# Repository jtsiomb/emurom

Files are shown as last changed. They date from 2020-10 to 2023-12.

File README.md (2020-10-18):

emurom - ROM emulator board
===========================

emurom photo

The purpose of emurom is to make it fast and convenient to hack code in ROMs
without having to repeatedly remove and reprogram an actual ROM chip.

Emurom is a board which connects through USB to a host computer, and
can be connected in place of a parallel ROM chip on a target device. It acts as
a ROM chip, but holds its data in a static RAM, which can be updated at any time
through the USB connection. Optionally it can provide power (5v) to the device
by shorting a jumper, and it also has a lead to clip to the reset signal of the
target device, to automatically reboot it when a new ROM image is uploaded.

Hardware design (kicad project) is in the root directory. The firmware for the
microcontroller is located under `fw`, while in the `emurom` subdirectory, there
is a UNIX program which can be used to upload a ROM image to the device, simply
by running it with the name of the ROM image as a command line argument.

 - Project website: http://nuclear.mutantstargoat.com/hw/emurom
 - Git repository: https://github.com/jtsiomb/emurom
 - Schematic (PDF): http://nuclear.mutantstargoat.com/hw/emurom/emurom-schematic.pdf

License
-------
Copyright (C) 2020 John Tsiombikas <nuclear@member.fsf.org>

All hardware designs in this project are free/open hardware. Feel free to
manufacture, sell, use, modify and/or redistribute, under the terms of the
Creative Commons Attribution Share-Alike license (CC BY-SA). See `LICENSE.hw`
for details.

All software in this project (firmware and host upload program) are free
software. Feel free to use, modify and/or redistribute under the terms of the
GNU General Public License version 3, or at your option any later version
published by the Free Software foundation. See `LICENSE.sw` for details.

Download
--------
This git repository contains the current project files and source code for
emurom, but it does not include any binaries or build products.

The release archive includes the schematic PDF, gerber files for PCB
manufacturing, datasheets, and pre-built binaries (firmware image and host
program).

Latest release (emurom rev2):
 - emurom website: http://nuclear.mutantstargoat.com/hw/emurom/release/emurom-rev2.tar.gz
 - github mirror: https://github.com/jtsiomb/emurom/releases/download/v2/emurom-rev2.tar.gz

Bill of materials
-----------------
Emurom rev2 BOM:

|#  | name | description | package |
|---|---|---|---|
| 1 | U1 | ATmega328P AVR microcontroller | TQFP 32 |
| 1 | U2 | MCP2221 USB-serial converter | SOIC 14 |
| 1 | U3 | 74HCT157 quad 2-1 multiplexer | SOIC 16 |
| 2 | U4,U5 | 74HCT595 8-bit shift register w/3-state output | SOIC 16 |
| 1 | U6 | UM61512AK 64k static RAM (or similar 64k SRAMs)| PDIP 32 |
| 3 | U7-U9 | 74HCT244 octal 3-state buffer | SOIC 20 |
| 2 | C1,C2 | 22 pF ceramic capacitor | 0805 |
|11 | C3-C13  | 0.1 uF ceramic capacitor | 0805 |
| 2 | R1,R2 | 330 Ohm resistor | 0805 |
| 6 | R3-R8 | 4.7 kOhm resistor | 0805 |
| 2 | D1,D2 | LED | 0805 |
| 2 | D3,D4 | 1N4148 signal diodes | 0805 |
| 1 | Y1 | 14.7456 quartz crystal | 7.6x4.1mm SMD |
| 3 | JP1-JP3 | 2-pin male header (jumper pins) | |
| 1 | J1 | 6-pin (2x3) male header or IDC conn. 2.54mm pitch | |
| 1 | J2 | molex 105017-1001 micro-USB (type B) connector | |
| 1 | U10,J3  | 24-pin (2x12) male header or IDC conn. 2.54mm pitch | |
| 1 | U11,J5  | 28-pin (2x14) male header or IDC conn. 2.54mm pitch | |
| 1 | J7 | 1-pin male header | |

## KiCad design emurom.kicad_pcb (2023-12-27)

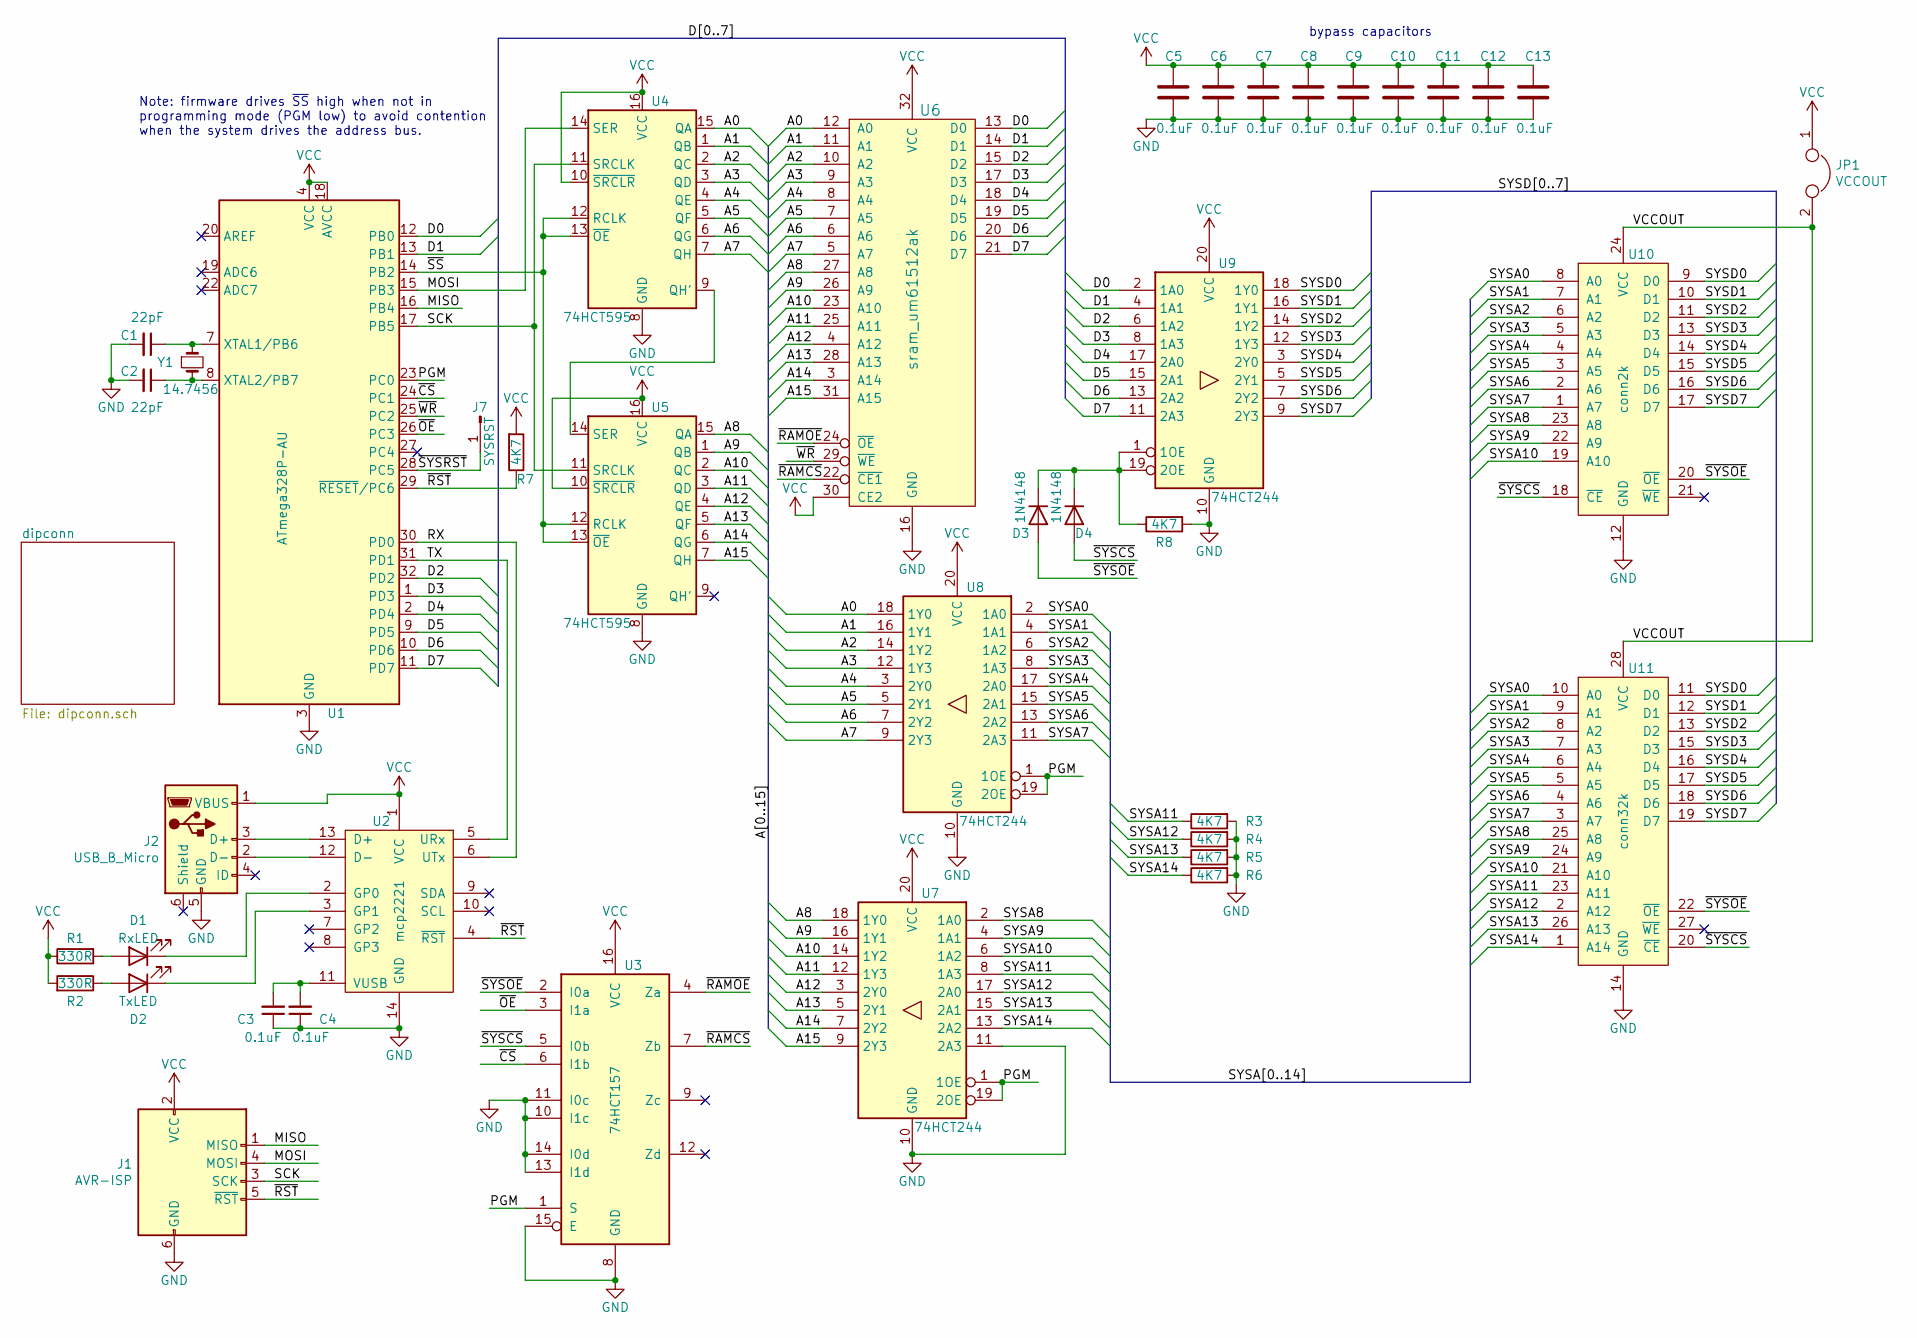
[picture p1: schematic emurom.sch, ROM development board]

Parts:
C1, C2: 22pF; C_0805_2012Metric_Pad1.15x1.40mm_HandSolder
C3, C4, C5, C6, C7, C8, C9, C10, C11, C12, C13: 0.1uF; C_0805_2012Metric_Pad1.15x1.40mm_HandSolder
D1: RxLED; LED_0805_2012Metric_Pad1.15x1.40mm_HandSolder
D2: TxLED; LED_0805_2012Metric_Pad1.15x1.40mm_HandSolder
D3, D4: 1N4148; D_0805_2012Metric_Pad1.15x1.40mm_HandSolder
J1: AVR-ISP; IDC-Header_2x03_P2.54mm_Vertical
J2: USB_B_Micro; USB_Micro-B_Molex-105017-0001
J7: SYSRST; PinSocket_1x01_P2.54mm_Vertical
JP1: VCCOUT; PinHeader_1x02_P2.54mm_Vertical
R1, R2: 330R; R_0805_2012Metric_Pad1.15x1.40mm_HandSolder
R3, R4, R5, R6, R7, R8: 4K7; R_0805_2012Metric_Pad1.15x1.40mm_HandSolder
U1: ATmega328P-AU; TQFP-32_7x7mm_P0.8mm
U2: mcp2221; SOIC-14_3.9x8.7mm_P1.27mm
U3: 74HCT157; SOIC-16_4.55x10.3mm_P1.27mm
U4, U5: 74HCT595; SOIC-16_3.9x9.9mm_P1.27mm
U6: sram_um61512ak; DIP-32_W7.62mm
U7, U8, U9: 74HCT244; SOIC-20W_7.5x12.8mm_P1.27mm
U10: conn2k
U11: conn32k
Y1: 14.7456; Crystal_SMD_ECS_CSM3X-2Pin_7.6x4.1mm

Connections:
/A0: U4.15 (QA), U6.12 (A0), U8.18 (1Y0)
/A1: U4.1 (QB), U6.11 (A1), U8.16 (1Y1)
/A2: U4.2 (QC), U6.10 (A2), U8.14 (1Y2)
/A3: U4.3 (QD), U6.9 (A3), U8.12 (1Y3)
/A4: U4.4 (QE), U6.8 (A4), U8.3 (2Y0)
/A5: U4.5 (QF), U6.7 (A5), U8.5 (2Y1)
/A6: U4.6 (QG), U6.6 (A6), U8.7 (2Y2)
/A7: U4.7 (QH), U6.5 (A7), U8.9 (2Y3)
/A8: U5.15 (QA), U6.27 (A8), U7.18 (1Y0)
/A9: U5.1 (QB), U6.26 (A9), U7.16 (1Y1)
/A10: U5.2 (QC), U6.23 (A10), U7.14 (1Y2)
/A11: U5.3 (QD), U6.25 (A11), U7.12 (1Y3)
/A12: U5.4 (QE), U6.4 (A12), U7.3 (2Y0)
/A13: U5.5 (QF), U6.28 (A13), U7.5 (2Y1)
/A14: U5.6 (QG), U6.3 (A14), U7.7 (2Y2)
/A15: U5.7 (QH), U6.31 (A15), U7.9 (2Y3)
/D0: U1.12 (PB0), U6.13 (D0), U9.2 (1A0)
/D1: U1.13 (PB1), U6.14 (D1), U9.4 (1A1)
/D2: U1.32 (PD2), U6.15 (D2), U9.6 (1A2)
/D3: U1.1 (PD3), U6.17 (D3), U9.8 (1A3)
/D4: U1.2 (PD4), U6.18 (D4), U9.17 (2A0)
/D5: U1.9 (PD5), U6.19 (D5), U9.15 (2A1)
/D6: U1.10 (PD6), U6.20 (D6), U9.13 (2A2)
/D7: U1.11 (PD7), U6.21 (D7), U9.11 (2A3)
/MISO: J1.1 (MISO), U1.16 (PB4)
/MOSI: J1.4 (MOSI), U1.15 (PB3), U4.14 (SER)
/PGM: U1.23 (PC0), U3.1 (S), U7.1 (1OE), U7.19 (2OE), U8.1 (1OE), U8.19 (2OE)
/RX: U1.30 (PD0), U2.6 (UTx)
/SCK: J1.3 (SCK), U1.17 (PB5), U4.11 (SRCLK), U5.11 (SRCLK)
/SYSA0: U8.2 (1A0), U10.8 (A0), U11.10 (A0)
/SYSA1: U8.4 (1A1), U10.7 (A1), U11.9 (A1)
/SYSA2: U8.6 (1A2), U10.6 (A2), U11.8 (A2)
/SYSA3: U8.8 (1A3), U10.5 (A3), U11.7 (A3)
/SYSA4: U8.17 (2A0), U10.4 (A4), U11.6 (A4)
/SYSA5: U8.15 (2A1), U10.3 (A5), U11.5 (A5)
/SYSA6: U8.13 (2A2), U10.2 (A6), U11.4 (A6)
/SYSA7: U8.11 (2A3), U10.1 (A7), U11.3 (A7)
/SYSA8: U7.2 (1A0), U10.23 (A8), U11.25 (A8)
/SYSA9: U7.4 (1A1), U10.22 (A9), U11.24 (A9)
/SYSA10: U7.6 (1A2), U10.19 (A10), U11.21 (A10)
/SYSA11: R3.1, U7.8 (1A3), U11.23 (A11)
/SYSA12: R4.1, U7.17 (2A0), U11.2 (A12)
/SYSA13: R5.1, U7.15 (2A1), U11.26 (A13)
/SYSA14: R6.1, U7.13 (2A2), U11.1 (A14)
/SYSD0: U9.18 (1Y0), U10.9 (D0), U11.11 (D0)
/SYSD1: U9.16 (1Y1), U10.10 (D1), U11.12 (D1)
/SYSD2: U9.14 (1Y2), U10.11 (D2), U11.13 (D2)
/SYSD3: U9.12 (1Y3), U10.13 (D3), U11.15 (D3)
/SYSD4: U9.3 (2Y0), U10.14 (D4), U11.16 (D4)
/SYSD5: U9.5 (2Y1), U10.15 (D5), U11.17 (D5)
/SYSD6: U9.7 (2Y2), U10.16 (D6), U11.18 (D6)
/SYSD7: U9.9 (2Y3), U10.17 (D7), U11.19 (D7)
/TX: U1.31 (PD1), U2.5 (URx)
/VCCOUT: JP1.2, U10.24 (VCC), U11.28 (VCC)
/~CS: U1.24 (PC1), U3.6 (I1b)
/~OE: U1.26 (PC3), U3.3 (I1a)
/~RAMCS: U3.7 (Zb), U6.22 (~CE1)
/~RAMOE: U3.4 (Za), U6.24 (~OE)
/~RST: J1.5 (~RST), R7.1, U1.29 (~RESET~/PC6), U2.4 (~RST)
/~SS: U1.14 (PB2), U4.12 (RCLK), U4.13 (~OE), U5.12 (RCLK), U5.13 (~OE)
/~SYSCS: D4.2 (A), U3.5 (I0b), U10.18 (~CE), U11.20 (~CE)
/~SYSOE: D3.2 (A), U3.2 (I0a), U10.20 (~OE), U11.22 (~OE)
/~SYSRST: J7.1, U1.28 (PC5)
/~WR: U1.25 (PC2), U6.29 (~WE)
GND: C1.2, C2.2, C3.1, C4.1, C5.2, C6.2, C7.2, C8.2, C9.2, C10.2, C11.2, C12.2, C13.2, J1.6 (GND), J2.5 (GND), R3.2, R4.2, R5.2, R6.2, R8.2, U1.3 (GND), U1.5 (GND), U1.21 (GND), U2.14 (GND), U3.8 (GND), U3.10 (I1c), U3.11 (I0c), U3.13 (I1d), U3.14 (I0d), U3.15 (E), U4.8 (GND), U5.8 (GND), U6.16 (GND), U7.10 (GND), U7.11 (2A3), U8.10 (GND), U9.10 (GND), U10.12 (GND), U11.14 (GND)
unnamed: C1.1, U1.7 (XTAL1/PB6), Y1.1
unnamed: C2.1, U1.8 (XTAL2/PB7), Y1.2
unnamed: C3.2, C4.2, U2.11 (VUSB)
unnamed: D1.1 (K), U2.2 (GP0)
unnamed: D1.2 (A), R1.2
unnamed: D2.1 (K), U2.3 (GP1)
unnamed: D2.2 (A), R2.1
unnamed: D3.1 (K), D4.1 (K), R8.1, U9.1 (1OE), U9.19 (2OE)
unnamed: J2.2 (D-), U2.12 (D-)
unnamed: J2.3 (D+), U2.13 (D+)
unnamed: U4.9 (QH'), U5.14 (SER)
VCC: C5.1, C6.1, C7.1, C8.1, C9.1, C10.1, C11.1, C12.1, C13.1, J1.2 (VCC), J2.1 (VBUS), JP1.1, R1.1, R2.2, R7.2, U1.4 (VCC), U1.6 (VCC), U1.18 (AVCC), U2.1 (VCC), U3.16 (VCC), U4.10 (~SRCLR), U4.16 (VCC), U5.10 (~SRCLR), U5.16 (VCC), U6.30 (CE2), U6.32 (VCC), U7.20 (VCC), U8.20 (VCC), U9.20 (VCC)

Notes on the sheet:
bypass capacitors
Note: firmware drives ~SS~ high when not in programming mode (PGM low) to avoid contention when the system drives the address bus.

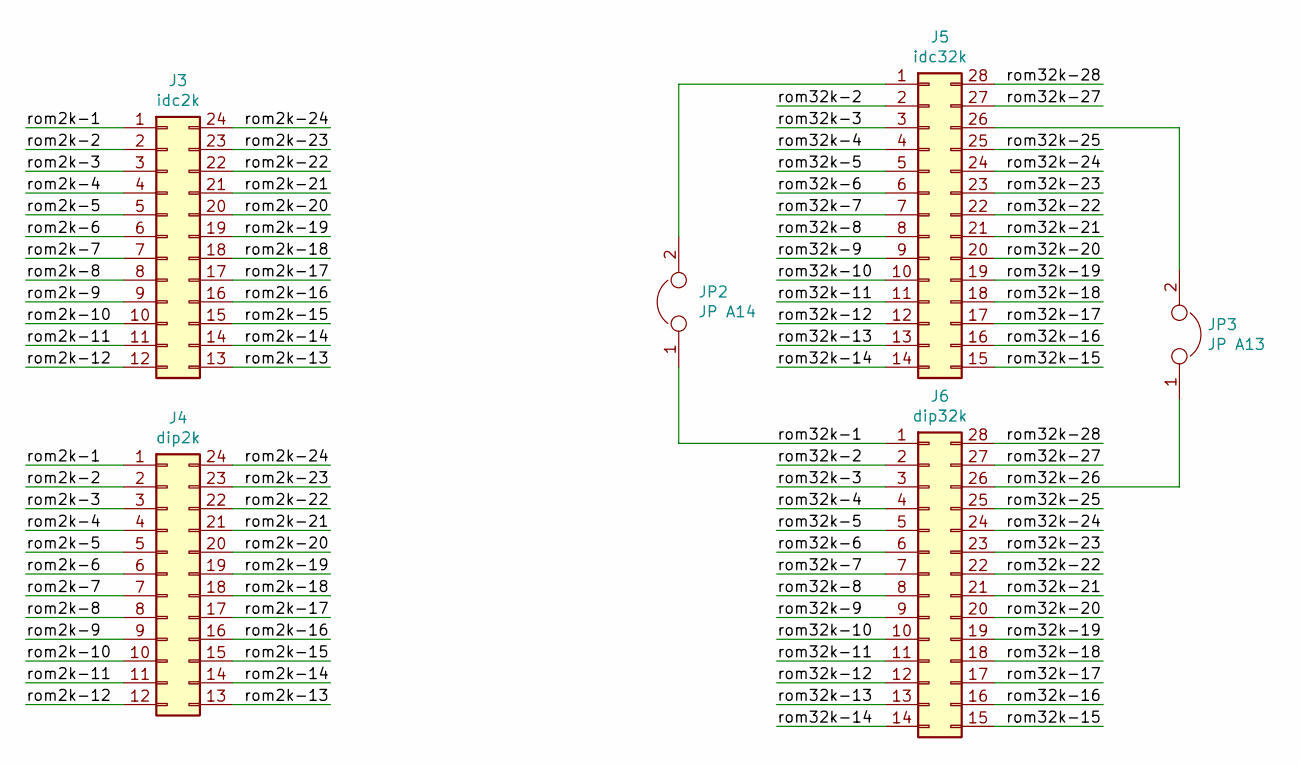
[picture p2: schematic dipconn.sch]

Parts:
J3: idc2k; conn2k
J4: dip2k; DIP-24_W15.24mm_Socket
J5: idc32k; conn32k
J6: dip32k; DIP-28_W15.24mm_Socket
JP2: JP A14; PinHeader_1x02_P2.54mm_Vertical
JP3: JP A13; PinHeader_1x02_P2.54mm_Vertical

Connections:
/dipconn/rom2k-1: J3.1, J4.1
/dipconn/rom2k-2: J3.2, J4.2
/dipconn/rom2k-3: J3.3, J4.3
/dipconn/rom2k-4: J3.4, J4.4
/dipconn/rom2k-5: J3.5, J4.5
/dipconn/rom2k-6: J3.6, J4.6
/dipconn/rom2k-7: J3.7, J4.7
/dipconn/rom2k-8: J3.8, J4.8
/dipconn/rom2k-9: J3.9, J4.9
/dipconn/rom2k-10: J3.10, J4.10
/dipconn/rom2k-11: J3.11, J4.11
/dipconn/rom2k-12: J3.12, J4.12
/dipconn/rom2k-13: J3.13, J4.13
/dipconn/rom2k-14: J3.14, J4.14
/dipconn/rom2k-15: J3.15, J4.15
/dipconn/rom2k-16: J3.16, J4.16
/dipconn/rom2k-17: J3.17, J4.17
/dipconn/rom2k-18: J3.18, J4.18
/dipconn/rom2k-19: J3.19, J4.19
/dipconn/rom2k-20: J3.20, J4.20
/dipconn/rom2k-21: J3.21, J4.21
/dipconn/rom2k-22: J3.22, J4.22
/dipconn/rom2k-23: J3.23, J4.23
/dipconn/rom2k-24: J3.24, J4.24
/dipconn/rom32k-1: J6.1, JP2.1
/dipconn/rom32k-2: J5.2, J6.2
/dipconn/rom32k-3: J5.3, J6.3
/dipconn/rom32k-4: J5.4, J6.4
/dipconn/rom32k-5: J5.5, J6.5
/dipconn/rom32k-6: J5.6, J6.6
/dipconn/rom32k-7: J5.7, J6.7
/dipconn/rom32k-8: J5.8, J6.8
/dipconn/rom32k-9: J5.9, J6.9
/dipconn/rom32k-10: J5.10, J6.10
/dipconn/rom32k-11: J5.11, J6.11
/dipconn/rom32k-12: J5.12, J6.12
/dipconn/rom32k-13: J5.13, J6.13
/dipconn/rom32k-14: J5.14, J6.14
/dipconn/rom32k-15: J5.15, J6.15
/dipconn/rom32k-16: J5.16, J6.16
/dipconn/rom32k-17: J5.17, J6.17
/dipconn/rom32k-18: J5.18, J6.18
/dipconn/rom32k-19: J5.19, J6.19
/dipconn/rom32k-20: J5.20, J6.20
/dipconn/rom32k-21: J5.21, J6.21
/dipconn/rom32k-22: J5.22, J6.22
/dipconn/rom32k-23: J5.23, J6.23
/dipconn/rom32k-24: J5.24, J6.24
/dipconn/rom32k-25: J5.25, J6.25
/dipconn/rom32k-26: J6.26, JP3.1
/dipconn/rom32k-27: J5.27, J6.27
/dipconn/rom32k-28: J5.28, J6.28
unnamed: J5.1, JP2.2
unnamed: J5.26, JP3.2

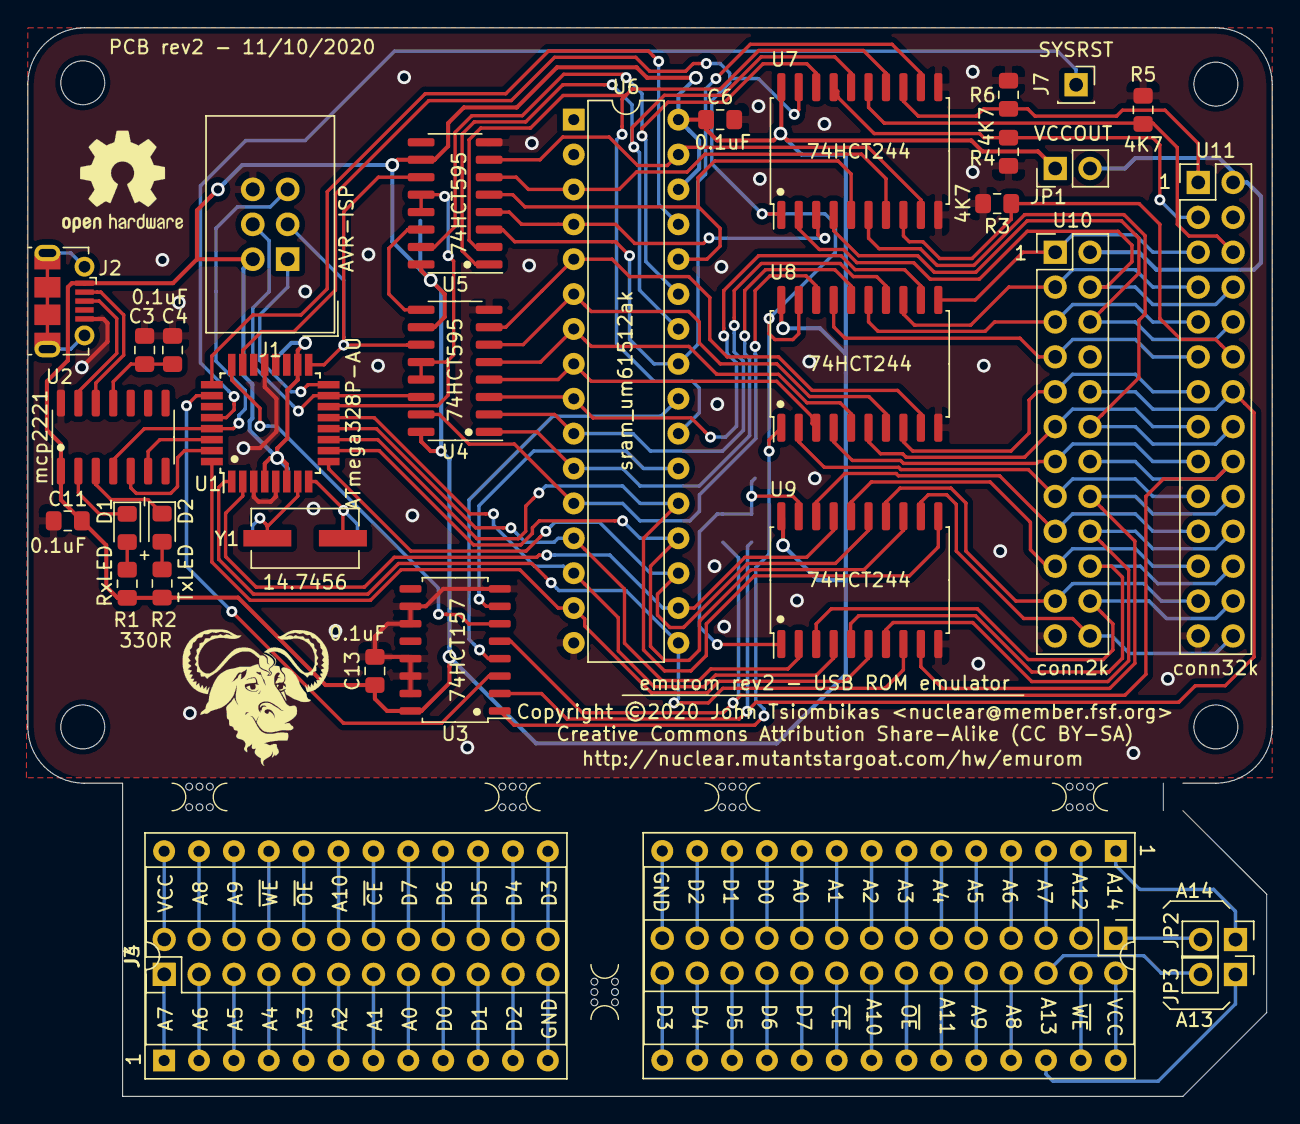
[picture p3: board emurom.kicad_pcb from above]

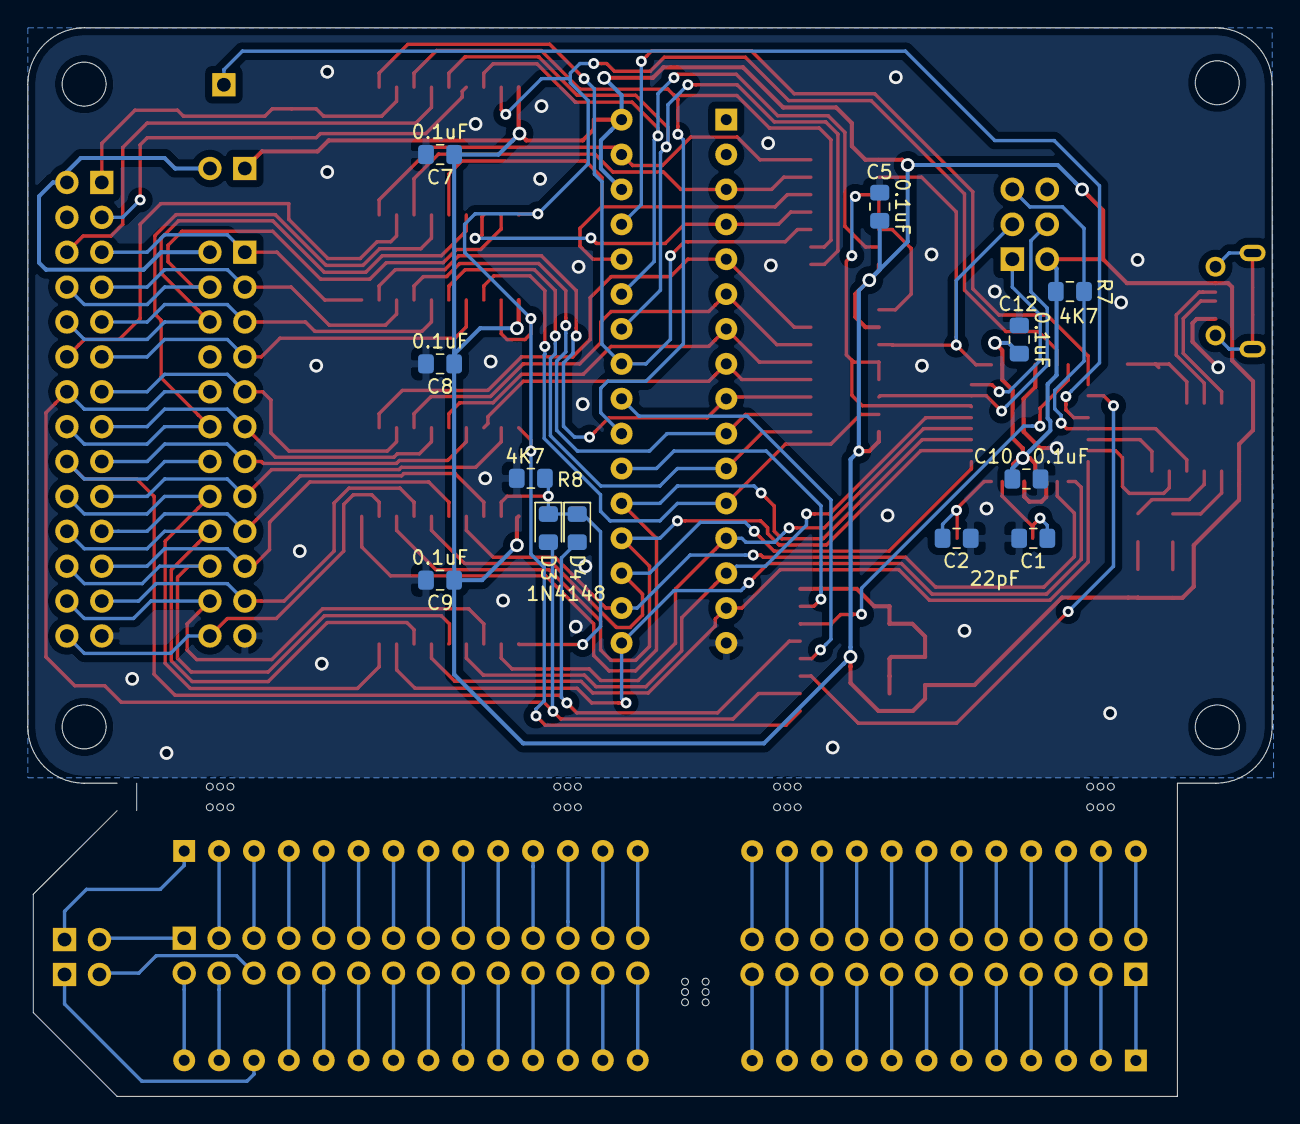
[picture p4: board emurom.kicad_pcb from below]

Board: 2 copper layers, 90.6 x 77.8 mm, 52 parts (12 on the bottom side), 131 nets.

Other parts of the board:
mouse-bite-2mm-slot, mouse-bite-2mm-slot#2, mouse-bite-2mm-slot#3, mouse-bite-2mm-slot#4, mouse-bite-2mm-slot#5: VAL**; mouse-bite-2mm-slot

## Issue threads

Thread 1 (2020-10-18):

The extra address line jumpers on the 32k/8k ROM breakout are too close to the IDC connector

jtsiomb, 2020-10-18:
The large ROM breakout board has the jumpers too close to the IDC connector, and they interfere with the cable.

Closed 2020-10-18.

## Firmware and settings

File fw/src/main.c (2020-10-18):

#include <stdio.h>
#include <stdlib.h>
#include <stdint.h>
#include <avr/io.h>
#include <avr/interrupt.h>
#include <util/delay.h>
#include "serial.h"

/* pin assignments
 * B[0,1]: D0,D1
 * D[2,7]: D2-D7
 * B2: SPI ~SS/shiftreg ~OE
 * B3: SPI MOSI
 * B4: SPI MISO (unused)
 * B5: SPI SCK
 * C0: programming mode PGM
 * C1: RAM ~CS
 * C2: RAM ~WE
 * C3: RAM ~OE
 * C5: ~SYSRST
 */
#define PB_SS		0x04
#define PB_MOSI		0x08
#define PB_MISO		0x10
#define PB_SCK		0x20
#define PC_PGM		0x01
#define PC_CS		0x02
#define PC_WE		0x04
#define PC_OE		0x08
#define PC_SYSRST	0x20

static void proc_cmd(char *input);
static void start_prog(void);
static void end_prog(void);
static void write_ram(uint16_t addr, uint8_t val);
static uint8_t read_ram(uint16_t addr);
static void dbg_setup_read(uint16_t addr);
static void set_data_bus(unsigned char val);
static void release_data_bus(void);
static void set_addr_bus(uint16_t addr);
static void sys_reset(void);
static inline void iodelay(void);

static int echo;
static int progmode;
static uint16_t addr;

static char input[128];
static unsigned char inp_cidx;


int main(void)
{
	/* SPI (SS/MOSI/SCK) are outputs */
	DDRB = PB_SS | PB_MOSI | PB_SCK;
	PORTB = PB_SS;	/* drive SS high when not in programming mode */
	DDRC = 0xff;	/* control signals are all outputs */
	PORTC = PC_CS | PC_WE | PC_OE | PC_SYSRST;
	DDRD = 0;	/* tri-state the data bus by default (high 6 bits, low 2 are in DDRB) */
	PORTD = 0;

	/* disable all pullups */
	MCUCR |= 1 << PUD;

	/* enable SPI (used to talk to the address bus shift registers)
	 * SPI master mode, clock / 16, CPOL=0/CPHA=0 because shiftreg clocks on the
	 * rising edge, and MSB first
	 */
	SPCR = (1 << SPE) | (1 << MSTR) | (1 << SPR0);

	/* init the serial port we use to talk to the host */
	init_serial(38400);
	sei();

	for(;;) {
		if(have_input()) {
			int c = getchar();
			if(echo) {
				putchar(c);
			}

			if(c == '\r' || c == '\n') {
				input[inp_cidx] = 0;
				proc_cmd(input);
				inp_cidx = 0;
			} else if(inp_cidx < sizeof input - 1) {
				input[inp_cidx++] = c;
			}
		}
	}
	return 0;
}

static void proc_cmd(char *input)
{
	char *endp;
	int data;

	switch(input[0]) {
	case 'e':
		echo = input[1] == '1' ? 1 : 0;
		printf("OK echo %s\n", echo ? "on" : "off");
		break;

	case 'p':
		if(progmode) {
			puts("ERR already in programming mode");
		} else {
			start_prog();
			puts("OK programming mode");
		}
		break;

	case 'b':
		puts("OK booting");
		if(!progmode) {
			sys_reset();
		} else {
			end_prog();
		}
		break;

	case 'a':
		addr = strtol(input + 1, &endp, 0);
		printf("OK address: %x\n", (unsigned int)addr);
		break;

	case 'w':
		if(!progmode) {
			puts("ERR not in programming mode");
			break;
		}
		data = strtol(input + 1, &endp, 0);
		write_ram(addr++, data);
		puts("OK");
		break;

	case 'r':
		if(!progmode) {
			puts("ERR not in programming mode");
			break;
		}
		data = read_ram(addr++);
		printf("OK %d\n", (int)data);
		break;

	case 'R':
		if(!progmode) {
			puts("ERR not in programming mode");
			break;
		}
		dbg_setup_read(addr);
		printf("OK set up read from %x\n", (unsigned int)addr);
		break;

	case 'A':
		if(!progmode) {
			puts("ERR not in programming mode");
			break;
		}
		addr = strtol(input + 1, &endp, 0);
		set_addr_bus(addr);
		printf("OK DBG address %x\n", (unsigned int)addr);
		break;

	case '?':
		puts("OK command help");
		puts(" e 0|1: turn echo on/off");
		puts(" p: enter programming mode");
		puts(" b: exit programming mode and boot up");
		puts(" a <addr>: set address counter (0-ffff)");
		puts(" w <data>: store data byte and increment address (0-255)");
		puts(" r: read data byte and increment address");
		puts(" ?: print command help");
		printf("Currently in %s mode\n", progmode ? "programming" : "boot");
		break;

	default:
		printf("ERR unknown command: '%c'\n", input[0]);
	}
}

static void start_prog(void)
{
	/* hold reset low, and take over the RAM */
	PORTC &= ~PC_SYSRST;
	PORTC |= PC_PGM;

	progmode = 1;
}

static void end_prog(void)
{
	/* make extra sure we don't drive the data bus */
	release_data_bus();

	/* PGM low and return reset and SS high */
	PORTB |= PB_SS;
	PORTC &= ~PC_PGM;
	PORTC |= PC_SYSRST | PC_CS | PC_OE;

	progmode = 0;
}

static void write_ram(uint16_t addr, uint8_t val)
{
	set_addr_bus(addr);
	set_data_bus(val);
	PORTC |= PC_OE;
	PORTC &= ~(PC_WE | PC_CS);
	iodelay();
	PORTC |= PC_CS;
	PORTC |= PC_WE;
	release_data_bus();
}

static uint8_t read_ram(uint16_t addr)
{
	uint8_t val;
	set_addr_bus(addr);
	PORTC |= PC_WE;
	PORTC &= ~(PC_CS | PC_OE);
	iodelay();
	val = (PIND & 0xfc) | (PINB & 3);
	PORTC |= PC_CS | PC_OE;
	return val;
}

static void dbg_setup_read(uint16_t addr)
{
	set_addr_bus(addr);
	PORTC |= PC_WE;
	PORTC &= ~(PC_CS | PC_OE);
}


static void set_data_bus(unsigned char val)
{
	/* drive the data bus */
	DDRD = 0xff;
	DDRB |= 3;
	PORTB = (PORTB & 0xfc) | (val & 3);
	PORTD = val;
}

static void release_data_bus(void)
{
	DDRD = 0;
	DDRB &= 0xfc;

	PORTD = 0;
	PORTB &= 0xfc;
}

static void set_addr_bus(uint16_t addr)
{
	PORTB &= ~PB_SS;
	SPDR = (uint8_t)(addr >> 8);
	while(!(SPSR & (1 << SPIF)));
	SPDR = (uint8_t)addr;
	while(!(SPSR & (1 << SPIF)));

	PORTB |= PB_SS;
	iodelay();
	PORTB &= ~PB_SS;	/* SS must return low because the shiftreg OE is tied to it */
}

static void sys_reset(void)
{
	PORTC &= ~PC_SYSRST;
	_delay_ms(500);
	PORTC |= PC_SYSRST;
}

static inline void iodelay(void)
{
	asm volatile("nop");
	asm volatile("nop");
	asm volatile("nop");
}

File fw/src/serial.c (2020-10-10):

#ifndef F_CPU
#ifdef XTAL
#define F_CPU	XTAL
#else
#warning "compiled for 1mhz internal rc osc. serial comms won't work"
#define F_CPU	1000000
#endif
#endif

#include <stdio.h>
#include <avr/io.h>
#include <avr/interrupt.h>
#include <util/delay.h>
#include <avr/power.h>

static int uart_send_char(char c, FILE *fp);
static int uart_get_char(FILE *fp);

#define BUF_SZ	16
#define BUF_IDX_MASK	(BUF_SZ - 1)
#define NEXT_IDX(x)	(((x) + 1) & BUF_IDX_MASK)
static char outbuf[BUF_SZ];
static volatile unsigned char out_rd, out_wr;
static char inbuf[BUF_SZ];
static volatile unsigned char in_rd, in_wr;

static FILE std_stream = FDEV_SETUP_STREAM(uart_send_char, uart_get_char, _FDEV_SETUP_RW);



void init_serial(long baud)
{
	unsigned int ubrr_val = F_CPU / 16 / baud - 1;

	power_usart0_enable();

	/* set baud generator timer reset value */
	UBRR0H = (unsigned char)(ubrr_val >> 8);
	UBRR0L = (unsigned char)ubrr_val;

	/* enable rx/tx and recv interrupt */
	UCSR0B = (1 << RXEN0) | (1 << TXEN0) | (1 << RXCIE0);
	/* set frame format: 8n1 */
	UCSR0C = 3 << UCSZ00;

	stdin = stdout = stderr = &std_stream;
}

int have_input(void)
{
	return in_wr != in_rd;
}

static int uart_send_char(char c, FILE *fp)
{
	/*int next;*/
	if(c == '\n') uart_send_char('\r', fp);

	while((UCSR0A & (1 << UDRE0)) == 0);
	UDR0 = (unsigned char)c;
#if 0
	next = NEXT_IDX(out_wr);
	while(next == out_rd);

	outbuf[out_wr] = c;
	out_wr = next;

	/* enable the Tx data register empty interrupt */
	UCSR0B |= 1 << UDRIE0;
#endif
	return 0;
}

static int uart_get_char(FILE *fp)
{
	char c;

	while(in_rd == in_wr);

	c = inbuf[in_rd];
	in_rd = NEXT_IDX(in_rd);
	return c;
}

ISR(USART_RX_vect)
{
	char c = UDR0;

	inbuf[in_wr] = c;
	in_wr = NEXT_IDX(in_wr);
}

/* USART Tx data register empty (can send more data) */
ISR(USART_UDRE_vect)
{
	if(out_rd != out_wr) {
		UDR0 = outbuf[out_rd];
		out_rd = NEXT_IDX(out_rd);
	} else {
		/* no more data to send for now, disable the interrupt */
		UCSR0B &= ~(1 << UDRIE0);
	}
}

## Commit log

2020-10-10 fixed swapped RX/TX lines
    [romdev.kicad_pcb, romdev.sch]
2020-10-10 - fixed mistake tying half the tri-state buffer bits to always on - fixed firmware bugs, now it can program and readback memory correctly
    [romdev.kicad_pcb, romdev.sch]
2020-10-13 fixed data bus output buffer enable
    [romdev.kicad_pcb, romdev.sch]
2020-10-18 renamed to emurom
    [dipconn.sch, emurom.kicad_pcb, emurom.sch]
2020-10-18 updated readme and schematic info
    [emurom.sch]
2020-10-18 - attempt to fix issue #1 about the address jumpers being too close to the IDC connector. - added BOM and release links to the README
    [emurom.kicad_pcb]
2023-12-27 version update
    [emurom.kicad_pcb]

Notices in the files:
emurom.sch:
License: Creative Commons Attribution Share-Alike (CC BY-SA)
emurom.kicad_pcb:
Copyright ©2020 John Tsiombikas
